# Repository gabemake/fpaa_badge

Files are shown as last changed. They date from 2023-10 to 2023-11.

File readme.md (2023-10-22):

# FPAA Add-on for SuperCon 2023 badge

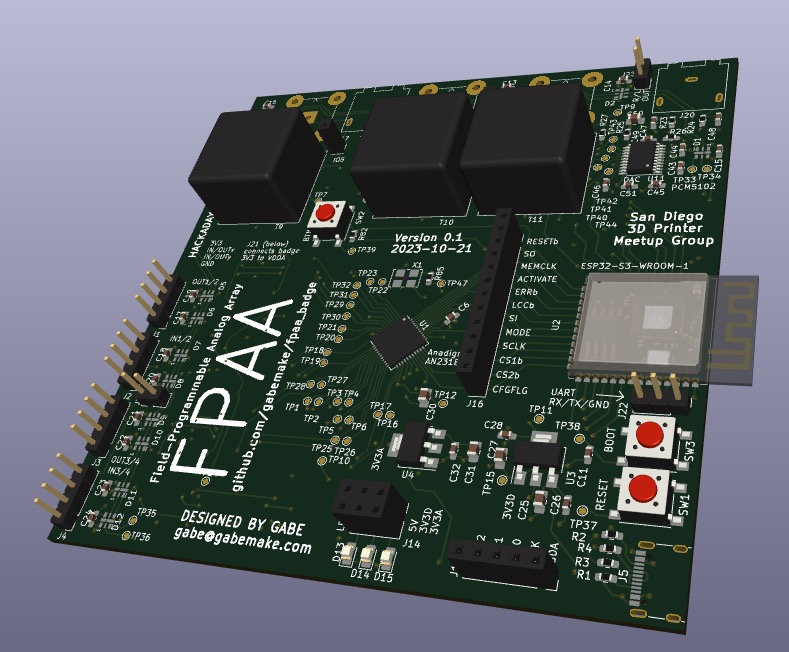
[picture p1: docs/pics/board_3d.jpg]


## SuperCon Badge info
Main article: https://hackaday.com/2023/10/18/2023-hackaday-supercon-badge-welcome-to-the-vectorscope/

Key points:
- RP2040 with DAC/ADC connected to PIOs
- Round display also on PIOs
- Micropython based SW

## FPAA Addon concept

What is an FPAA?
- Field-Programmable Analog Array
- Configurable array of analog components
  - Gain
  - Filter
  - Mix
  - more...
- 4 differential I and O ports
- 3 bidirectional differential ports
- SPI-ish configuration interface
- a.k.a. dpASP
- Datasheet: https://www.anadigm.com/_doc/DS231000-U001.pdf

Other things on the board:
- Connectors and single-to-differential conversion matching to badge IO
- ESP32-S3 to program FPAA (via web or otherwise)
- RBGLEDs all the way around
- a button
- BNC connectors + 3.5mm jack for external inputs or output
- SD Card reader

What to do with the addon?
- Figure out how to program and use a FPAA
- Maybe do a cool windows media player -like visualizer for music
- Get lots of practice soldering 0603 resistors

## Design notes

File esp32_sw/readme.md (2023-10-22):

# ESP32-S3 Software

Not yet started, but this is what I want to build:
- Simple web interface to upload config files for FPAA
- FPAA configuration interface (bit-bang SPI)
- RGB LED web interface (maybe tie in with FPAA configuration)
- ZRNA API (eventually)
- Web based scope to .wav converter (http://bummsn.de/osc_txt/)
- File manager for SD card (for wav files, etc.)
- Playback of .wav files via I2S DAC
- Custom SW for I2C/GPIO header
- Make button do something
- USB Host?
- Serial terminal?

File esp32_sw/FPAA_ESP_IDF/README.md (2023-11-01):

# FPAA Badge ESP32-S3 code

This code is based on a bunch of examples from the ESP-IDF github repo. 

file_server example is used to manage the web interface.
sdmmc is used to manage the file storage on the SD card (FAT FS for PC compatibility)
A highly modified spi_master LCD master example is used for the FPAA programming interface
I2S is used for the DAC.

### Status
- Wifi works with default SSID/IP, no configuration yet
- webserver is running with basic file management
- SPI writes can be sent with Program button on web page
- I2S initializes, but no file playback yet
- SD Card not working yet (need breakout board for dev kit)
- Internal SPI flash being used for web server
- platformio.ini locked to my serial port name, since my mac is picky

### TODO

in no particular order...

- add SD card and spi flash support
- add Wifi customization/configuration
- add SD card wifi configuration
- add background task for .wav playback
- add osc_wav page for text/drawing .wav "rendering"
- add basic RGB LED support
- test FPAA configuration
- add ace.js for file editing
- add RGB LED dynamic lighting for port enables, etc.
- add fun LED patterns
- add I2C to badge
- add button functionality (play/pause DAC?)

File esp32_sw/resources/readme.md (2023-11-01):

## Resources

In this folder, we have the following:
- `esp32-s3-devkitc-1-n8r2.json` file to add to `~/.platformio/boards`
- `test_mixer.ahf` as an example FPAA programming file

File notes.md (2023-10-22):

References:
- Differential to single-ended
  - https://www.analog.com/en/analog-dialogue/raqs/raq-issue-145.html

- ADC driver
  - https://www.analog.com/en/technical-articles/adc-driving-single-ended-to-differential-conversion.html

- FPAA Datasheet
  - https://www.anadigm.com/_doc/DS231000-U001.pdf

- FPAA User Manual
  - https://www.anadigm.com/_doc/UM000231-U001.pdf

- FPAA Product Page
  - https://www.anadigm.com/an231e04.asp

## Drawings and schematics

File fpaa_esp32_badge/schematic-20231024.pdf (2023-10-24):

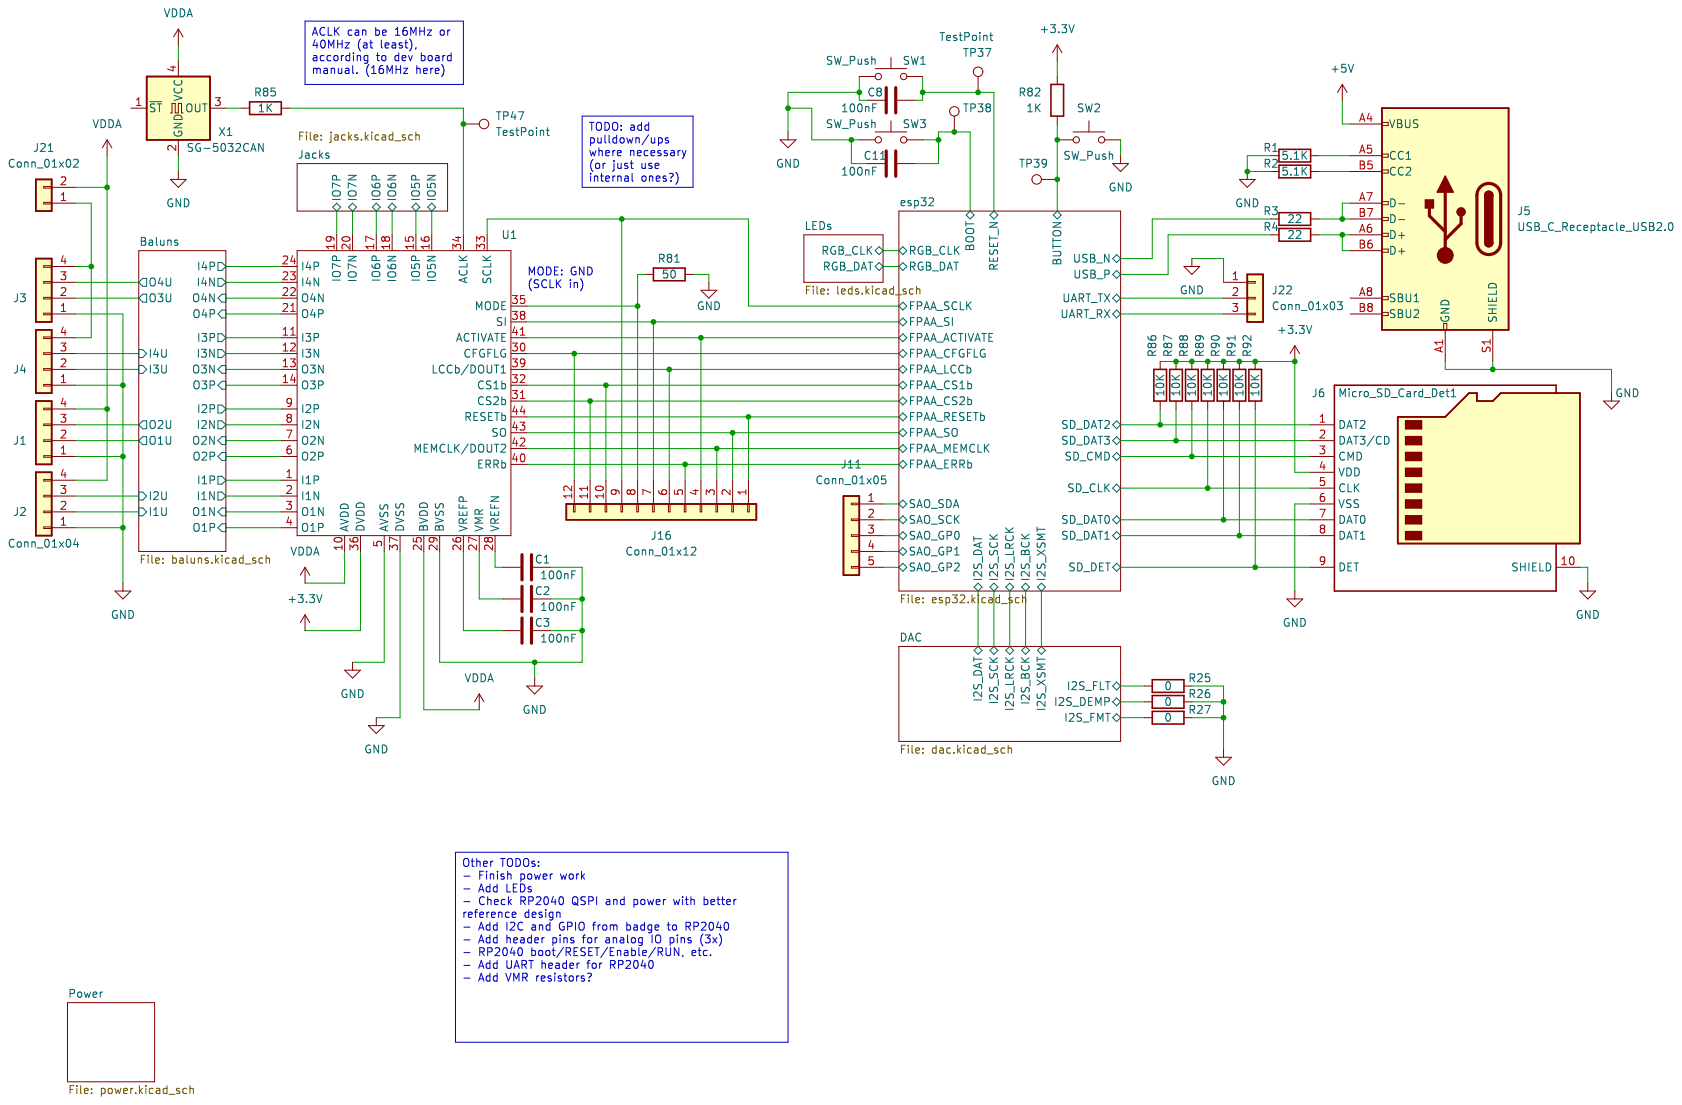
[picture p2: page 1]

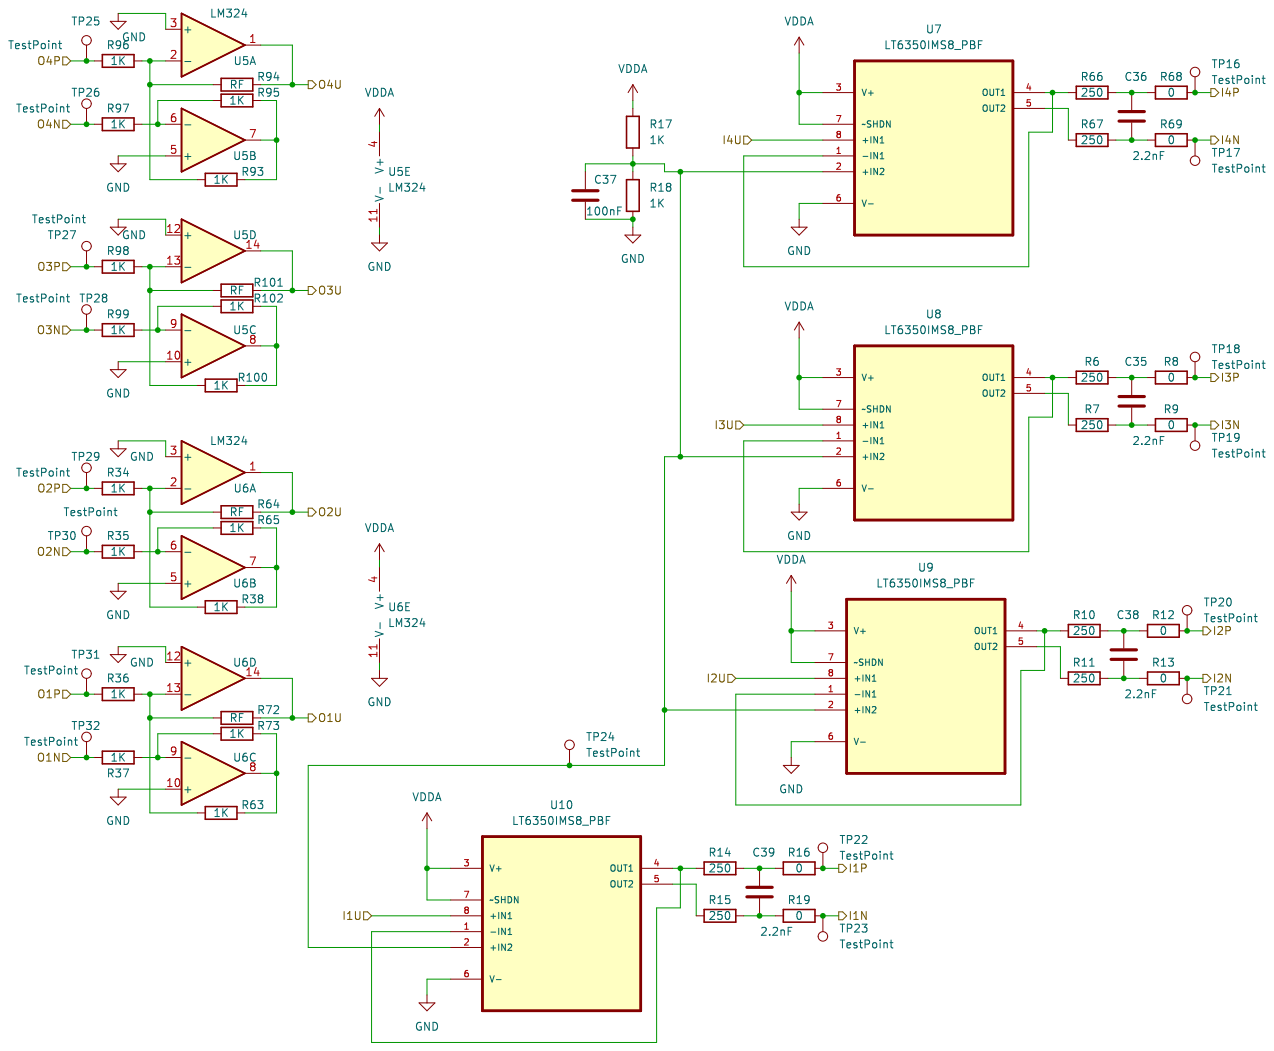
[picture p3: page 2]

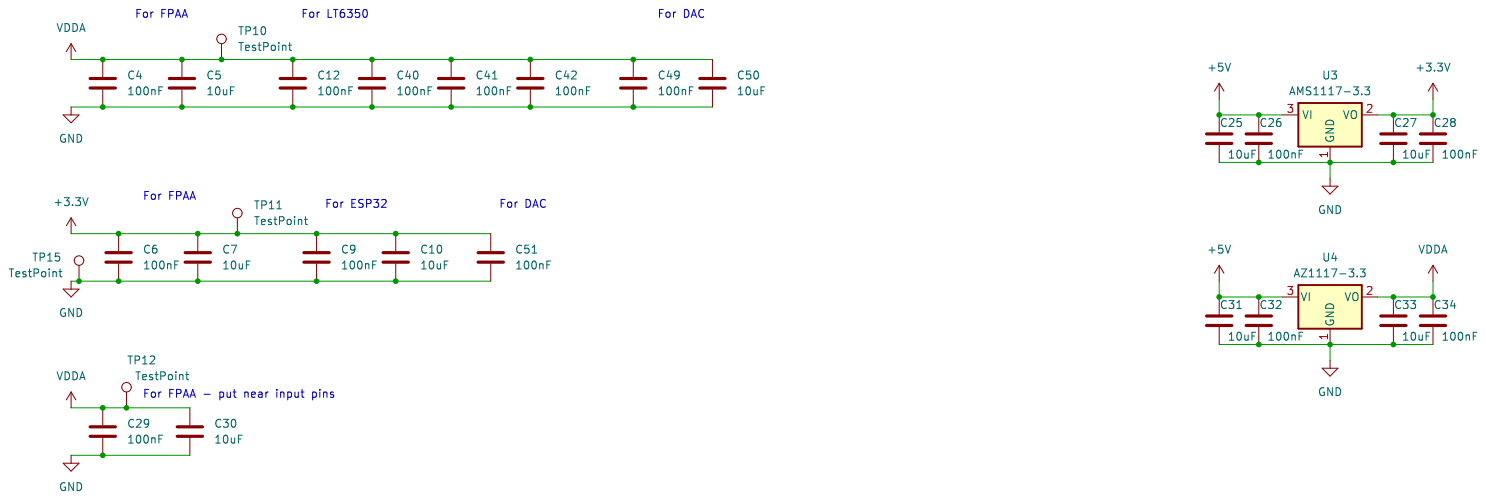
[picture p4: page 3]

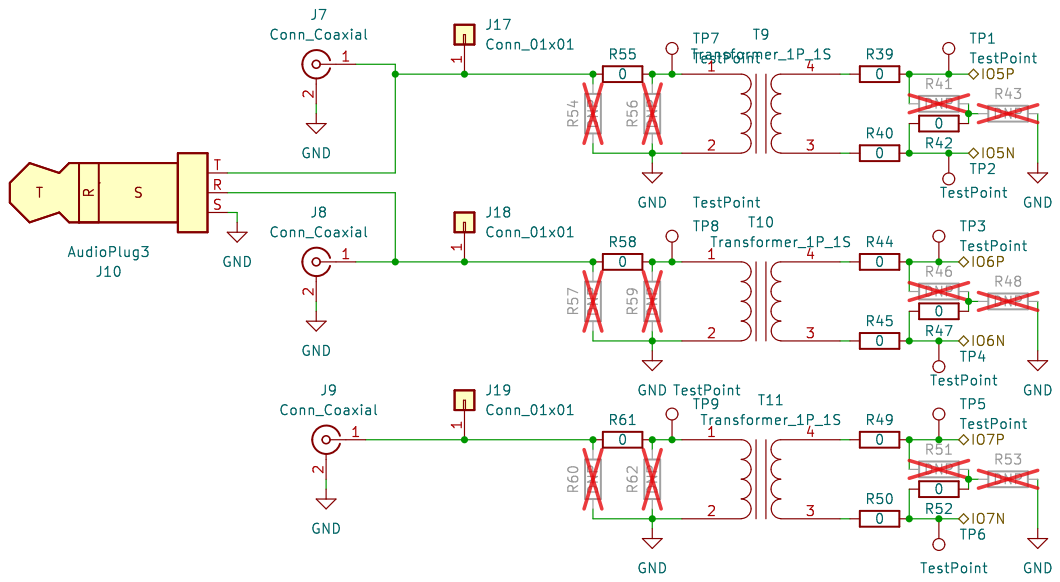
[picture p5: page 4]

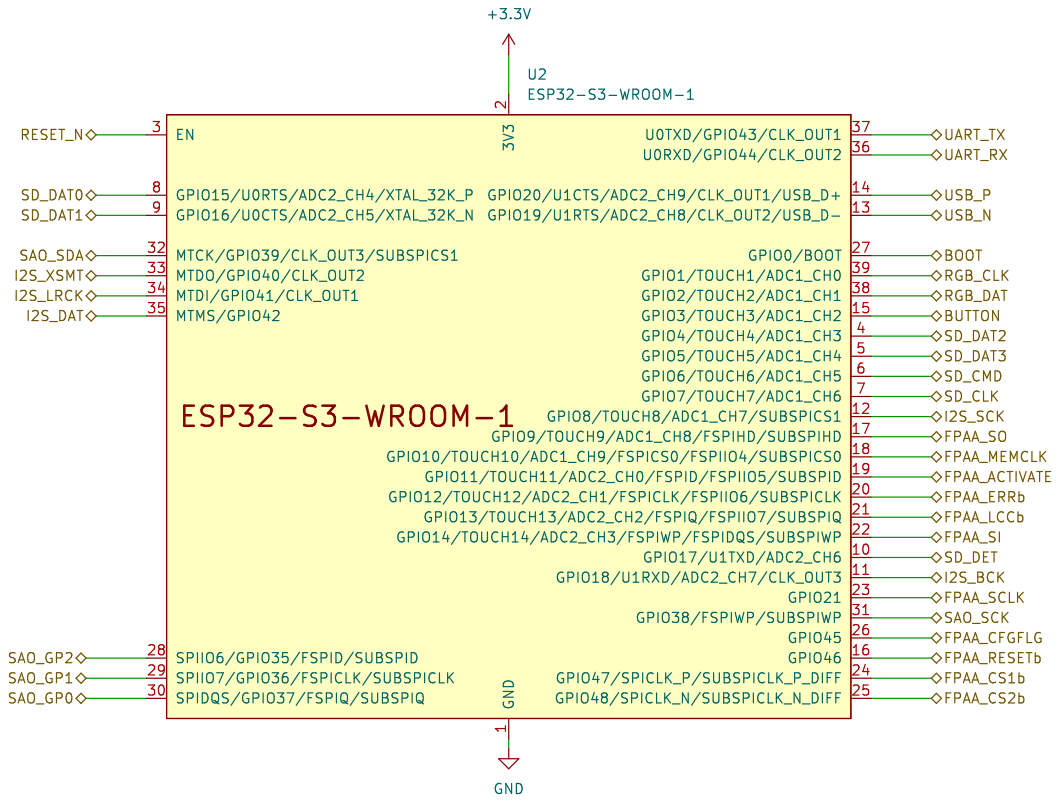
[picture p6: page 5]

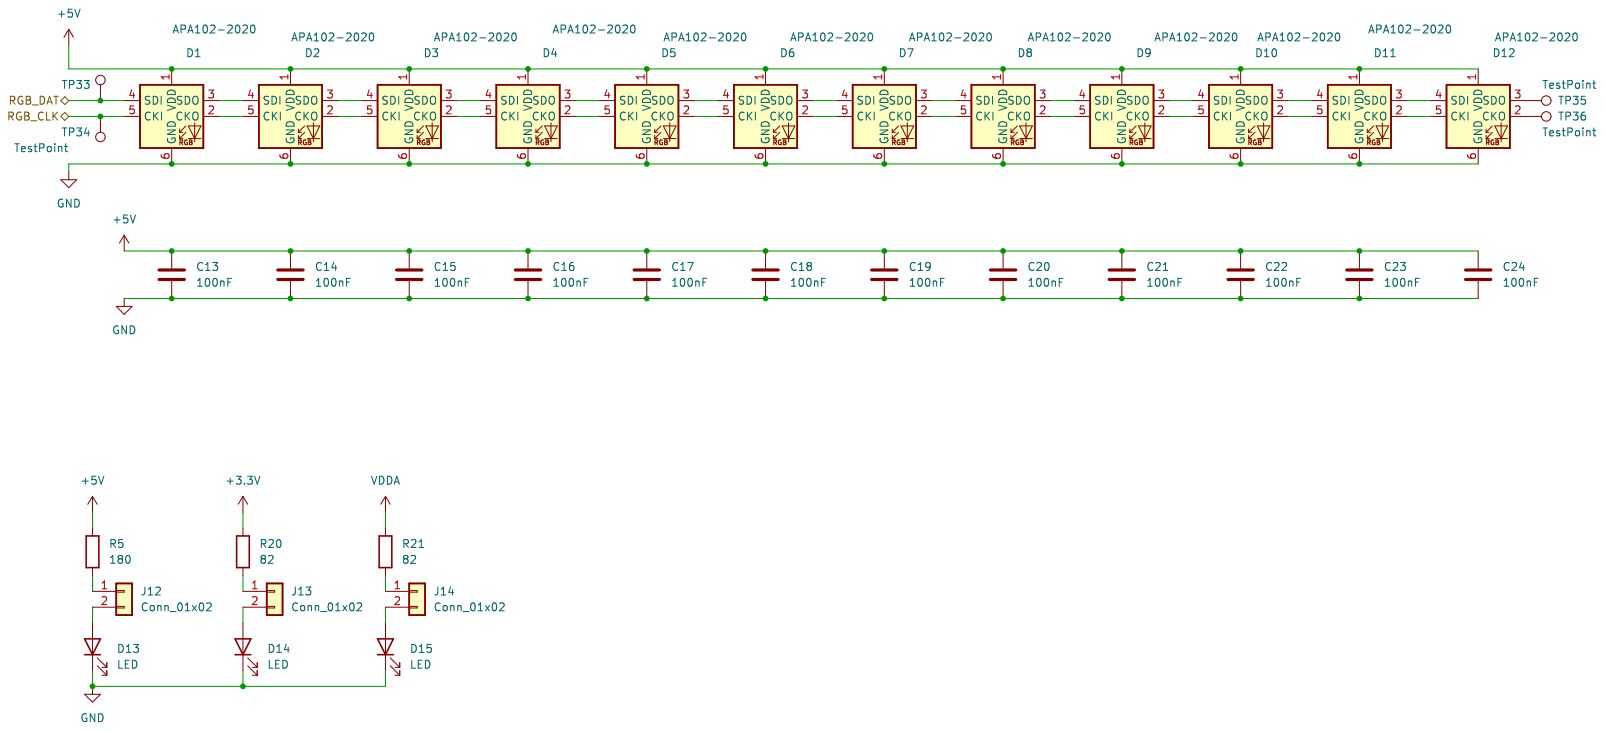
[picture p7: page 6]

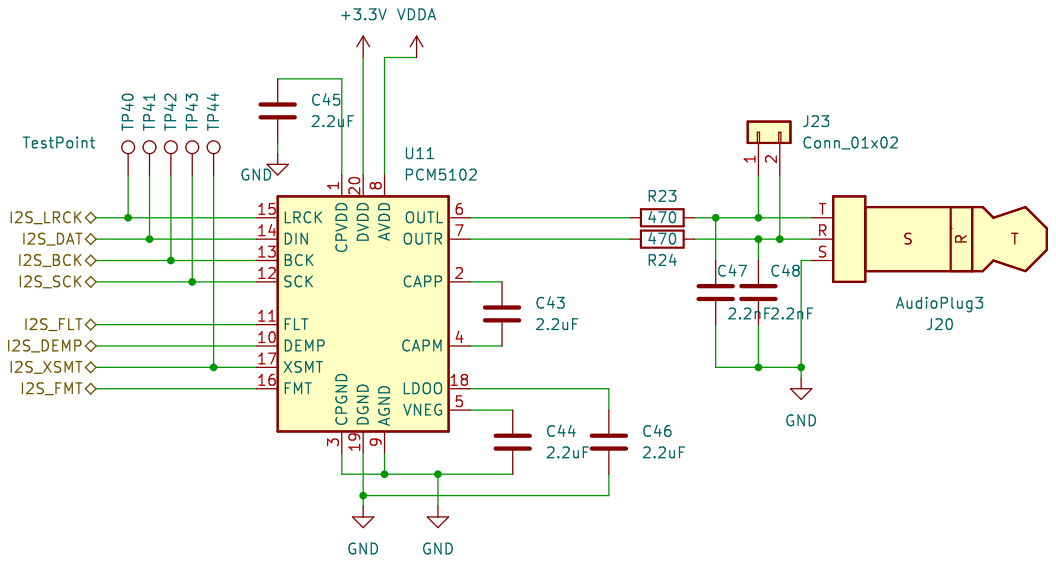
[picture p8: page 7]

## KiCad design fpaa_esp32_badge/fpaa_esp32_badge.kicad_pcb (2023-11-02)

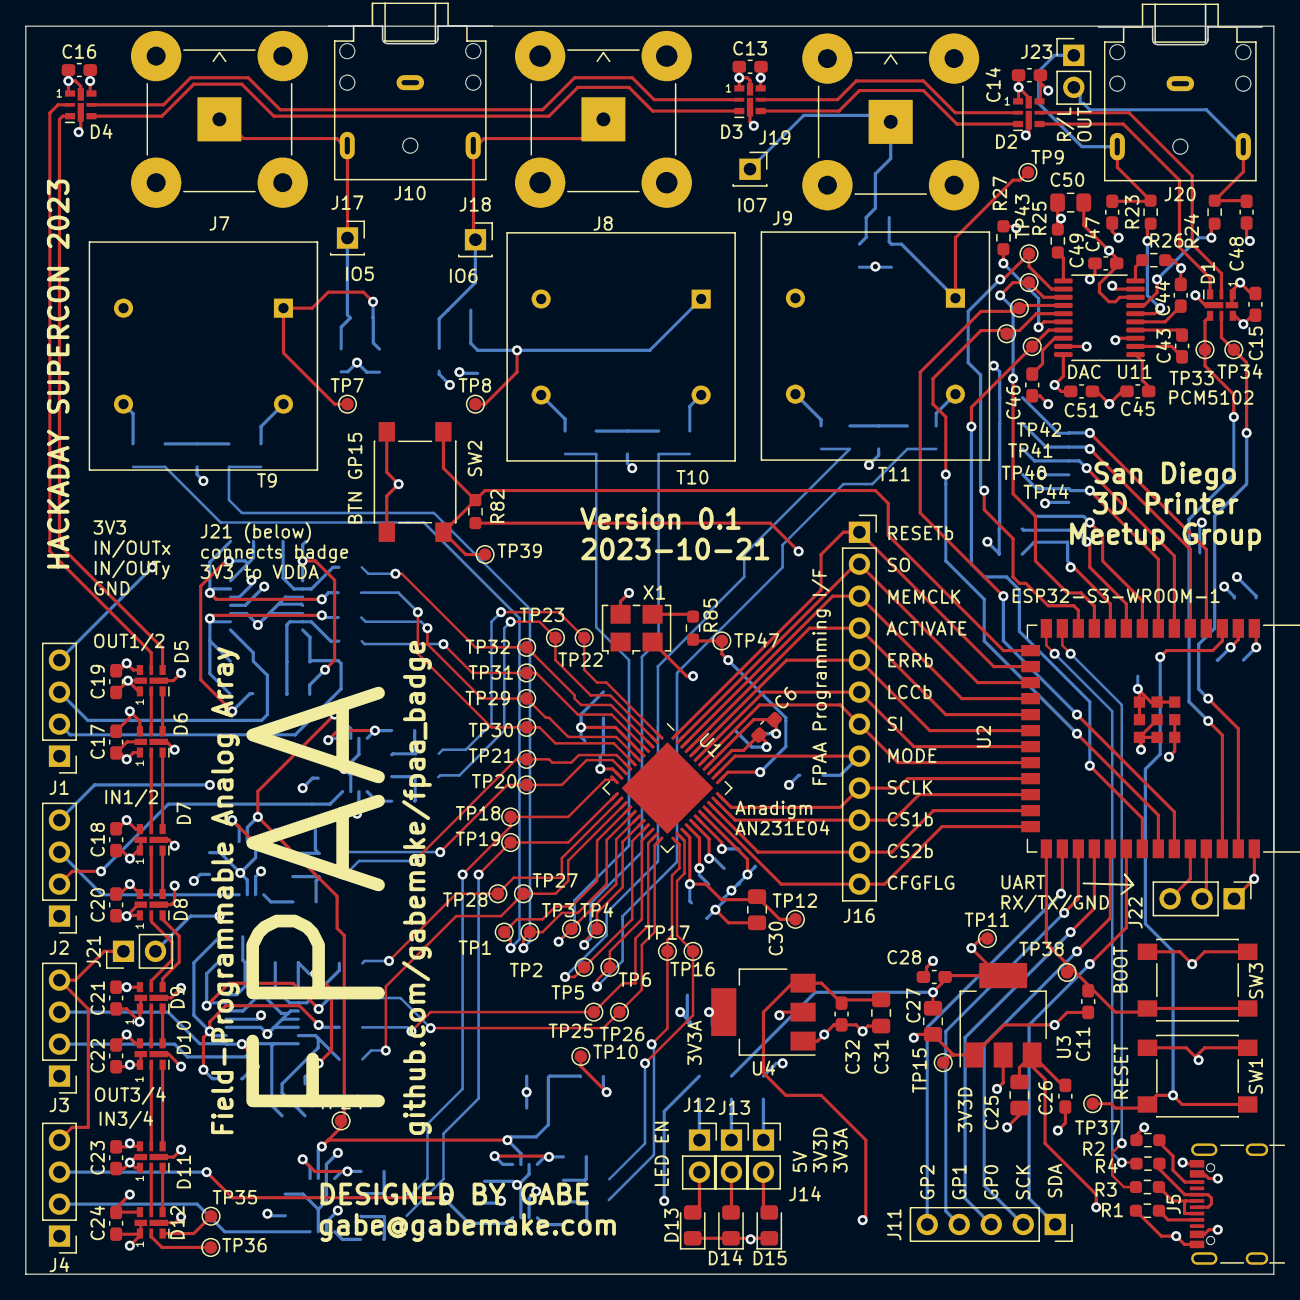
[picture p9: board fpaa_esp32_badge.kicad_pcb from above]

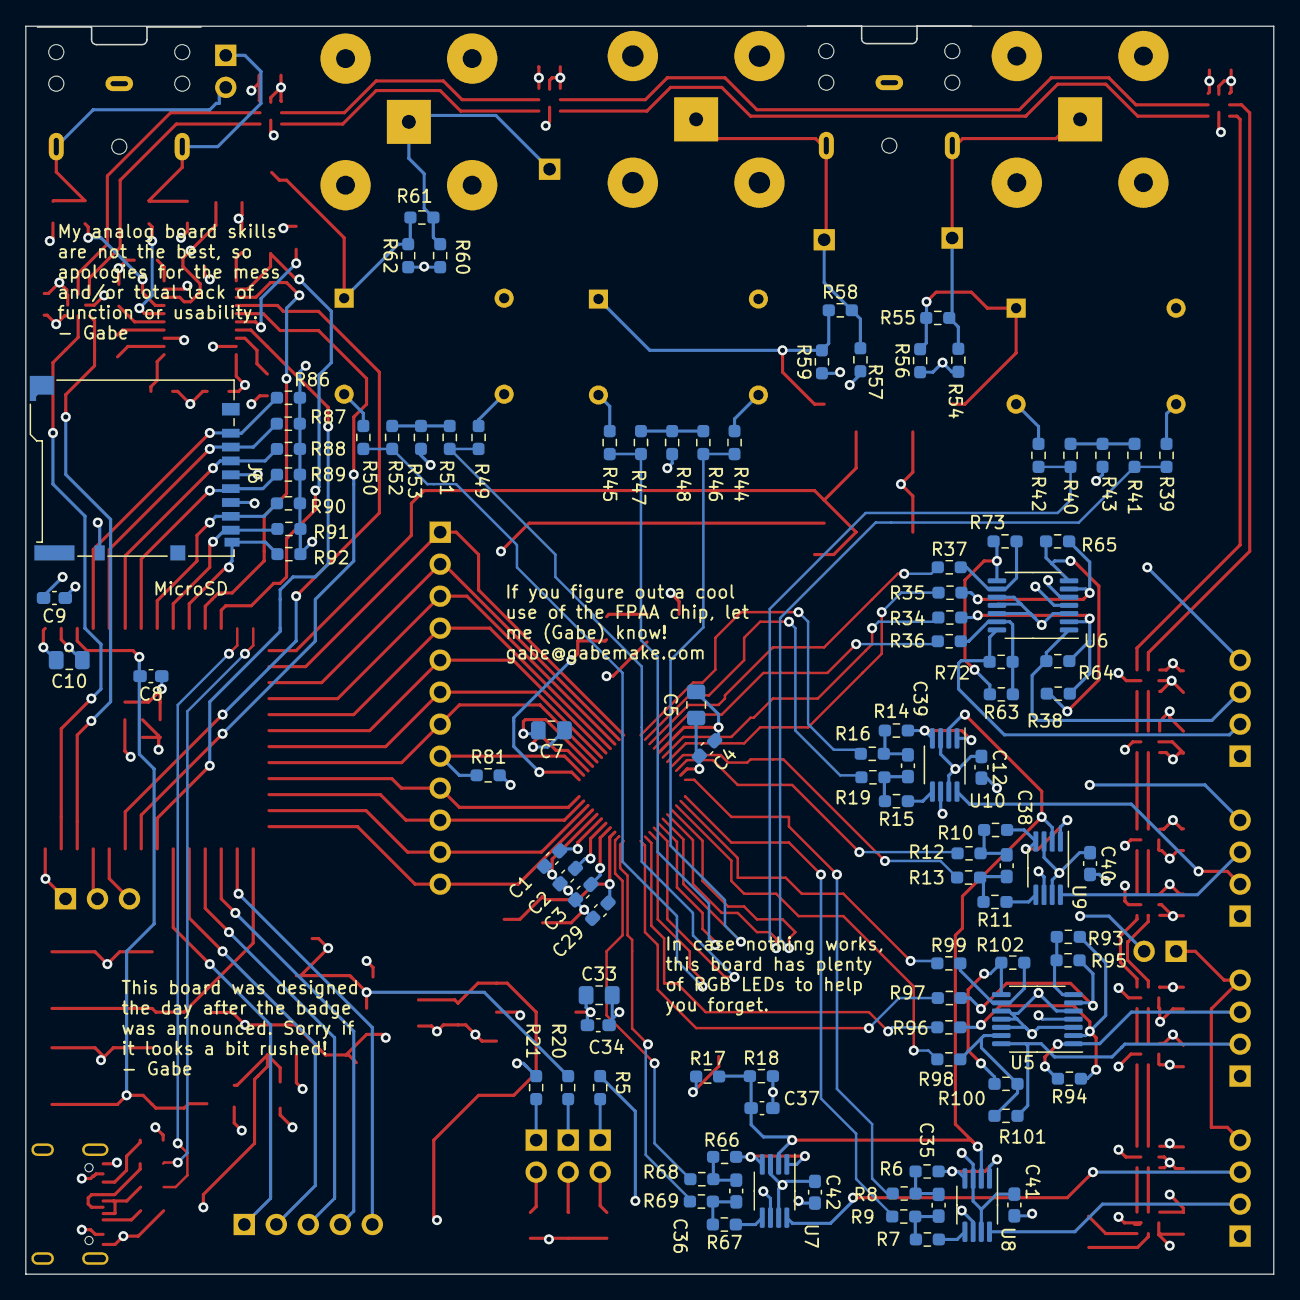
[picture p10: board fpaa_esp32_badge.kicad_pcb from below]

Board: 4 copper layers, 99.1 x 99.1 mm, 233 parts (101 on the bottom side), 168 nets.

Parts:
C1, C2, C3, C4, C6, C8, C9, C11, C12, C13, C14, C15, C16, C17, C18, C19, C20, C21, C22, C23, C24, C26, C28, C29, C32, C34, C37, C40, C41, C42, C49, C51: 100nF; C_0603_1608Metric_Pad1.08x0.95mm_HandSolder
C5, C7, C10, C25, C27, C30, C31, C33, C50: 10uF; C_0805_2012Metric_Pad1.18x1.45mm_HandSolder
C35, C36, C38, C39, C47, C48: 2.2nF; C_0603_1608Metric_Pad1.08x0.95mm_HandSolder
C43, C44, C45, C46: 2.2uF; C_0603_1608Metric_Pad1.08x0.95mm_HandSolder
D1, D2, D3, D4, D5, D6, D7, D8, D9, D10, D11, D12: APA102-2020; LED-APA102-2020
D13, D14, D15: LED; LED_0805_2012Metric_Pad1.15x1.40mm_HandSolder
J1, J2, J3, J4: Conn_01x04; PinHeader_1x04_P2.54mm_Vertical
J5: USB_C_Receptacle_USB2.0; USB_C_Receptacle_GCT_USB4105-xx-A_16P_TopMnt_Horizontal
J6: Micro_SD_Card_Det1; microSD_HC_Hirose_DM3BT-DSF-PEJS
J7, J9: Conn_Coaxial; BNC_TEConnectivity_1478035_Horizontal
J8: Conn_Coaxial; BNC_Molex_SD-73131-024_Horizontal
J10, J20: AudioPlug3; Jack_3.5mm_CUI_SJ1-3523N_Horizontal
J11: Conn_01x05; PinSocket_1x05_P2.54mm_Vertical
J12, J13, J14: Conn_01x02; PinSocket_1x02_P2.54mm_Vertical
J16: Conn_01x12; PinSocket_1x12_P2.54mm_Vertical
J17, J18, J19: Conn_01x01; PinSocket_1x01_P2.54mm_Vertical
J21, J23: Conn_01x02; PinHeader_1x02_P2.54mm_Vertical
J22: Conn_01x03; PinHeader_1x03_P2.54mm_Vertical
R1, R2: 5.1K; R_0603_1608Metric_Pad0.98x0.95mm_HandSolder
R3, R4: 22; R_0603_1608Metric_Pad0.98x0.95mm_HandSolder
R5: 180; R_0603_1608Metric_Pad0.98x0.95mm_HandSolder
R6, R7, R10, R11, R14, R15, R66, R67: 250; R_0603_1608Metric_Pad0.98x0.95mm_HandSolder
R8, R9, R12, R13, R16, R19, R25, R26, R27, R39, R40, R42, R44, R45, R47, R49, R50, R52, R55, R58, R61, R68, R69: 0; R_0603_1608Metric_Pad0.98x0.95mm_HandSolder
R17, R18, R34, R35, R36, R37, R38, R63, R65, R73, R82, R85, R93, R95, R96, R97, R98, R99, R100, R102: 1K; R_0603_1608Metric_Pad0.98x0.95mm_HandSolder
R20, R21: 82; R_0603_1608Metric_Pad0.98x0.95mm_HandSolder
R23, R24: 470; R_0603_1608Metric_Pad0.98x0.95mm_HandSolder
R41, R43, R46, R48, R51, R53, R54, R56, R57, R59, R60, R62: DNP; R_0603_1608Metric_Pad0.98x0.95mm_HandSolder
R64, R72, R94, R101: RF; R_0603_1608Metric_Pad0.98x0.95mm_HandSolder
R81: 50; R_0603_1608Metric_Pad0.98x0.95mm_HandSolder
R86, R87, R88, R89, R90, R91, R92: 10K; R_0603_1608Metric_Pad0.98x0.95mm_HandSolder
SW1, SW2, SW3: SW_Push; SW_SPST_PTS645
T9, T10, T11: Transformer_1P_1S; Transformer_NF_ETAL_1-1_P1200
TP1, TP2, TP3, TP4, TP5, TP6, TP7, TP8, TP9, TP10, TP11, TP12, TP15, TP16, TP17, TP18, TP19, TP20, TP21, TP22, TP23, TP24, TP25, TP26, TP27, TP28, TP29, TP30, TP31, TP32, TP33, TP34, TP35, TP36, TP37, TP38, TP39, TP40, TP41, TP42, TP43, TP44, TP47: TestPoint; TestPoint_Pad_D1.0mm
U1: QFN-44-1EP_7x7mm_P0.5mm_EP5.15x5.15mm
U2: ESP32-S3-WROOM-1
U3: AMS1117-3.3; SOT-223-3_TabPin2
U4: AZ1117-3.3; SOT-223-3_TabPin2
U5, U6: LM324; TSSOP-14_4.4x5mm_P0.65mm
U7, U8, U9, U10: LT6350IMS8_PBF; MSOP-8_3x3mm_P0.65mm
U11: PCM5102; TSSOP-20_4.4x6.5mm_P0.65mm
X1: SG-5032CAN; Oscillator_SMD_SeikoEpson_SG8002LB-4Pin_5.0x3.2mm

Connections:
+3.3V: C6.1, C7.1, C9.1, C10.1, C27.1, C28.1, C51.1, J6.4 (VDD), R20.1, R82.1, R86.2, R87.2, R88.2, R89.2, R90.2, R91.2, R92.2, TP11.1, U1.36 (DVDD), U2.2 (3V3), U3.2 (VO), U11.20 (DVDD)
+5V: C13.1, C14.1, C15.1, C16.1, C17.1, C18.1, C19.1, C20.1, C21.1, C22.1, C23.1, C24.1, C25.1, C26.1, C31.1, C32.1, D1.1 (VDD), D2.1 (VDD), D3.1 (VDD), D4.1 (VDD), D5.1 (VDD), D6.1 (VDD), D7.1 (VDD), D8.1 (VDD), D9.1 (VDD), D10.1 (VDD), D11.1 (VDD), D12.1 (VDD), J5.A4 (VBUS), J5.A9 (VBUS), J5.B4 (VBUS), J5.B9 (VBUS), R5.1, U3.3 (VI), U4.3 (VI)
/Baluns/I1N: R19.2, TP23.1, U1.2 (I1N)
/Baluns/I1P: R16.2, TP22.1, U1.1 (I1P)
/Baluns/I1U: J2.2, U10.8 (+IN1)
/Baluns/I2N: R13.2, TP21.1, U1.8 (I2N)
/Baluns/I2P: R12.2, TP20.1, U1.9 (I2P)
/Baluns/I2U: J2.3, U9.8 (+IN1)
/Baluns/I3N: R9.2, TP19.1, U1.12 (I3N)
/Baluns/I3P: R8.2, TP18.1, U1.11 (I3P)
/Baluns/I3U: J4.2, U8.8 (+IN1)
/Baluns/I4N: R69.2, TP17.1, U1.23 (I4N)
/Baluns/I4P: R68.2, TP16.1, U1.24 (I4P)
/Baluns/I4U: J4.3, U7.8 (+IN1)
/Baluns/O1N: R37.1, TP32.1, U1.3 (O1N)
/Baluns/O1P: R36.1, TP31.1, U1.4 (O1P)
/Baluns/O1U: J1.2, R72.2, U6.14
/Baluns/O2N: R35.1, TP30.1, U1.7 (O2N)
/Baluns/O2P: R34.1, TP29.1, U1.6 (O2P)
/Baluns/O2U: J1.3, R64.2, U6.1
/Baluns/O3N: R99.1, TP28.1, U1.13 (O3N)
/Baluns/O3P: R98.1, TP27.1, U1.14 (O3P)
/Baluns/O3U: J3.2, R101.2, U5.14
/Baluns/O4N: R97.1, TP26.1, U1.22 (O4N)
/Baluns/O4P: R96.1, TP25.1, U1.21 (O4P)
/Baluns/O4U: J3.3, R94.2, U5.1
/DAC/I2S_BCK: TP42.1, U2.11 (GPIO18/U1RXD/ADC2_CH7/CLK_OUT3), U11.13 (BCK)
/DAC/I2S_DAT: TP41.1, U2.35 (MTMS/GPIO42), U11.14 (DIN)
/DAC/I2S_DEMP: R26.1, U11.10 (DEMP)
/DAC/I2S_FLT: R25.1, U11.11 (FLT)
/DAC/I2S_FMT: R27.1, U11.16 (FMT)
/DAC/I2S_LRCK: TP40.1, U2.34 (MTDI/GPIO41/CLK_OUT1), U11.15 (LRCK)
/DAC/I2S_SCK: TP43.1, U2.12 (GPIO8/TOUCH8/ADC1_CH7/SUBSPICS1), U11.12 (SCK)
/DAC/I2S_XSMT: TP44.1, U2.33 (MTDO/GPIO40/CLK_OUT2), U11.17 (XSMT)
/Jacks/IO5N: R40.2, R42.1, TP2.1, U1.16 (IO5N)
/Jacks/IO5P: R39.2, R41.1, TP1.1, U1.15 (IO5P)
/Jacks/IO6N: R45.2, R47.1, TP4.1, U1.18 (IO6N)
/Jacks/IO6P: R44.2, R46.1, TP3.1, U1.17 (IO6P)
/Jacks/IO7N: R50.2, R52.1, TP6.1, U1.20 (IO7N)
/Jacks/IO7P: R49.2, R51.1, TP5.1, U1.19 (IO7P)
/LEDs/RGB_CLK: D1.5 (CKI), TP34.1, U2.39 (GPIO1/TOUCH1/ADC1_CH0)
/LEDs/RGB_DAT: D1.4 (SDI), TP33.1, U2.38 (GPIO2/TOUCH2/ADC1_CH1)
/esp32/BOOT: C11.2, SW3.1, TP38.1, U2.27 (GPIO0/BOOT)
/esp32/BUTTON: R82.2, SW2.1, TP39.1, U2.15 (GPIO3/TOUCH3/ADC1_CH2)
/esp32/FPAA_ACTIVATE: J16.4, U1.41 (ACTIVATE), U2.19 (GPIO11/TOUCH11/ADC2_CH0/FSPID/FSPIIO5/S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)
/esp32/FPAA_CFGFLG: J16.12, U1.30 (CFGFLG), U2.26 (GPIO45)
/esp32/FPAA_CS1b: J16.10, U1.32 (CS1b), U2.24 (GPIO47/SPICLK_P/SUBSPICLK_P_DIFF)
/esp32/FPAA_CS2b: J16.11, U1.31 (CS2b), U2.25 (GPIO48/SPICLK_N/SUBSPICLK_N_DIFF)
/esp32/FPAA_ERRb: J16.5, U1.40 (ERRb), U2.20 (GPIO12/TOUCH12/ADC2_CH1/FSPICLK/FSPIIO6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)
/esp32/FPAA_LCCb: J16.6, U1.39 (LCCb/DOUT1), U2.21 (GPIO13/TOUCH13/ADC2_CH2/FSPIQ/FSPIIO7/S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)
/esp32/FPAA_MEMCLK: J16.3, U1.42 (MEMCLK/DOUT2), U2.18 (GPIO10/TOUCH10/ADC1_CH9/FSPICS0/FSPIIO4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)
/esp32/FPAA_RESETb: J16.1, U1.44 (RESETb), U2.16 (GPIO46)
/esp32/FPAA_SCLK: J16.9, U1.33 (SCLK), U2.23 (GPIO21)
/esp32/FPAA_SI: J16.7, U1.38 (SI), U2.22 (GPIO14/TOUCH14/ADC2_CH3/FSPIWP/FSPIDQS/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)
/esp32/FPAA_SO: J16.2, U1.43 (SO), U2.17 (GPIO9/TOUCH9/ADC1_CH8/FSPIHD/SUBSPIHD)
/esp32/RESET_N: C8.2, SW1.1, TP37.1, U2.3 (EN)
/esp32/SAO_GP0: J11.3, U2.30 (SPIDQS/GPIO37/FSPIQ/SUBSPIQ)
/esp32/SAO_GP1: J11.4, U2.29 (SPIIO7/GPIO36/FSPICLK/SUBSPICLK)
/esp32/SAO_GP2: J11.5, U2.28 (SPIIO6/GPIO35/FSPID/SUBSPID)
/esp32/SAO_SCK: J11.2, U2.31 (GPIO38/FSPIWP/SUBSPIWP)
/esp32/SAO_SDA: J11.1, U2.32 (MTCK/GPIO39/CLK_OUT3/SUBSPICS1)
/esp32/SD_CLK: J6.5 (CLK), R89.1, U2.7 (GPIO7/TOUCH7/ADC1_CH6)
/esp32/SD_CMD: J6.3 (CMD), R88.1, U2.6 (GPIO6/TOUCH6/ADC1_CH5)
/esp32/SD_DAT0: J6.7 (DAT0), R90.1, U2.8 (GPIO15/U0RTS/ADC2_CH4/XTAL_32K_P)
/esp32/SD_DAT1: J6.8 (DAT1), R91.1, U2.9 (GPIO16/U0CTS/ADC2_CH5/XTAL_32K_N)
/esp32/SD_DAT2: J6.1 (DAT2), R86.1, U2.4 (GPIO4/TOUCH4/ADC1_CH3)
/esp32/SD_DAT3: J6.2 (DAT3/CD), R87.1, U2.5 (GPIO5/TOUCH5/ADC1_CH4)
/esp32/SD_DET: J6.9 (DET), R92.1, U2.10 (GPIO17/U1TXD/ADC2_CH6)
/esp32/UART_RX: J22.3, U2.36 (U0RXD/GPIO44/CLK_OUT2)
/esp32/UART_TX: J22.2, U2.37 (U0TXD/GPIO43/CLK_OUT1)
/esp32/USB_N: R3.1, U2.13 (GPIO19/U1RTS/ADC2_CH8/CLK_OUT2/USB_D-)
/esp32/USB_P: R4.1, U2.14 (GPIO20/U1CTS/ADC2_CH9/CLK_OUT1/USB_D+)
GND: C1.2, C2.1, C3.2, C4.2, C5.2, C6.2, C7.2, C8.1, C9.2, C10.2, C11.1, C12.2, C13.2, C14.2, C15.2, C16.2, C17.2, C18.2, C19.2, C20.2, C21.2, C22.2, C23.2, C24.2, C25.2, C26.2, C27.2, C28.2, C29.2, C30.2, C31.2, C32.2, C33.2, C34.2, C37.2, C40.2, C41.2, C42.2, C44.2, C45.2, C46.2, C47.2, C48.2, C49.2, C50.2, C51.2, D1.6 (GND), D2.6 (GND), D3.6 (GND), D4.6 (GND), D5.6 (GND), D6.6 (GND), D7.6 (GND), D8.6 (GND), D9.6 (GND), D10.6 (GND), D11.6 (GND), D12.6 (GND), D13.1 (K), D14.1 (K), D15.1 (K), J1.1, J2.1, J3.1, J4.1, J5.A1 (GND), J5.A12 (GND), J5.B1 (GND), J5.B12 (GND), J5.S1 (SHIELD), J6.6 (VSS), J6.10 (SHIELD), J7.2 (Ext), J8.2 (Ext), J9.2 (Ext), J10.S, J20.S, J22.1, R1.1, R2.1, R18.2, R25.2, R26.2, R27.2, R43.2, R48.2, R53.2, R54.1, R56.1, R57.1, R59.1, R60.1, R62.1, R81.2, SW1.2, SW2.2, SW3.2, TP15.1, U1.5 (AVSS), U1.29 (BVSS), U1.37 (DVSS), U2.1 (GND), U2.40 (GND), U2.41 (GND), U3.1 (GND), U4.1 (GND), U5.3 (+), U5.5 (+), U5.10 (+), U5.11 (V-), U5.12 (+), U6.3 (+), U6.5 (+), U6.10 (+), U6.11 (V-), U6.12 (+), U7.6 (V-), U8.6 (V-), U9.6 (V-), U10.6 (V-), U11.3 (CPGND), U11.9 (AGND), U11.19 (DGND), X1.2 (GND)
unnamed: C35.1, R6.2, R8.1
unnamed: C35.2, R7.2, R9.1
unnamed: C36.1, R66.2, R68.1
unnamed: C36.2, R67.2, R69.1
unnamed: C38.1, R10.2, R12.1
unnamed: C38.2, R11.2, R13.1
unnamed: C39.1, R14.2, R16.1
unnamed: C39.2, R15.2, R19.1
unnamed: D1.2 (CKO), D2.5 (CKI)
unnamed: D1.3 (SDO), D2.4 (SDI)
unnamed: D2.2 (CKO), D3.5 (CKI)
unnamed: D2.3 (SDO), D3.4 (SDI)
unnamed: D3.2 (CKO), D4.5 (CKI)
unnamed: D3.3 (SDO), D4.4 (SDI)
unnamed: D4.2 (CKO), D5.5 (CKI)
unnamed: D4.3 (SDO), D5.4 (SDI)
unnamed: D5.2 (CKO), D6.5 (CKI)
unnamed: D5.3 (SDO), D6.4 (SDI)
unnamed: D6.2 (CKO), D7.5 (CKI)
unnamed: D6.3 (SDO), D7.4 (SDI)
unnamed: D7.2 (CKO), D8.5 (CKI)
unnamed: D7.3 (SDO), D8.4 (SDI)
unnamed: D8.2 (CKO), D9.5 (CKI)
unnamed: D8.3 (SDO), D9.4 (SDI)
unnamed: D9.2 (CKO), D10.5 (CKI)
unnamed: D10.2 (CKO), D11.5 (CKI)
unnamed: D9.3 (SDO), D10.4 (SDI)
unnamed: D10.3 (SDO), D11.4 (SDI)
unnamed: D11.2 (CKO), D12.5 (CKI)
unnamed: D11.3 (SDO), D12.4 (SDI)
unnamed: D12.2 (CKO), TP36.1
unnamed: D12.3 (SDO), TP35.1
unnamed: D13.2 (A), J12.2
unnamed: D14.2 (A), J13.2
unnamed: D15.2 (A), J14.2
unnamed: J5.A5 (CC1), R1.2
unnamed: J5.B5 (CC2), R2.2
unnamed: J5.A6 (D+), J5.B6 (D+), R4.2
unnamed: J5.A7 (D-), J5.B7 (D-), R3.2
unnamed: J12.1, R5.2
unnamed: J13.1, R20.2
unnamed: J14.1, R21.2
unnamed: J16.8, R81.1, U1.35 (MODE)
unnamed: J7.1 (In), J10.T, J17.1, R54.2, R55.1
unnamed: J8.1 (In), J10.R, J18.1, R57.2, R58.1
unnamed: J9.1 (In), J19.1, R60.2, R61.1
unnamed: J3.4, J4.4, J21.1
unnamed: C47.1, J20.T, J23.1, R23.2
unnamed: C48.1, J20.R, J23.2, R24.2
unnamed: R38.2, R65.2, U6.7
unnamed: R41.2, R42.2, R43.1
unnamed: R46.2, R47.2, R48.1
unnamed: R51.2, R52.2, R53.1
unnamed: R63.2, R73.2, U6.8
unnamed: R93.2, R95.2, U5.7
unnamed: R100.2, R102.2, U5.8
unnamed: R55.2, R56.2, T9.1 (AA), TP7.1
unnamed: R40.1, T9.3 (SA)
unnamed: R39.1, T9.4 (SB)
unnamed: R58.2, R59.2, T10.1 (AA), TP8.1
unnamed: R45.1, T10.3 (SA)
unnamed: R44.1, T10.4 (SB)
unnamed: R61.2, R62.2, T11.1 (AA), TP9.1
unnamed: R50.1, T11.3 (SA)
unnamed: R49.1, T11.4 (SB)
unnamed: R85.2, TP47.1, U1.34 (ACLK)
unnamed: C2.2, U1.27 (VMR)
unnamed: C1.1, U1.28 (VREFN)
unnamed: C3.1, U1.26 (VREFP)
unnamed: R93.1, R94.1, R96.2, U5.2 (-)
unnamed: R95.1, R97.2, U5.6 (-)
unnamed: R99.2, R102.1, U5.9 (-)
unnamed: R98.2, R100.1, R101.1, U5.13 (-)
unnamed: R34.2, R38.1, R64.1, U6.2 (-)
unnamed: R35.2, R65.1, U6.6 (-)
unnamed: R37.2, R73.1, U6.9 (-)
unnamed: R36.2, R63.1, R72.1, U6.13 (-)
unnamed: R66.1, U7.1 (-IN1), U7.4 (OUT1)
unnamed: R67.1, U7.5 (OUT2)
unnamed: R6.1, U8.1 (-IN1), U8.4 (OUT1)
unnamed: R7.1, U8.5 (OUT2)
unnamed: R10.1, U9.1 (-IN1), U9.4 (OUT1)
unnamed: R11.1, U9.5 (OUT2)
unnamed: C37.1, R17.2, R18.1, TP24.1, U7.2 (+IN2), U8.2 (+IN2), U9.2 (+IN2), U10.2 (+IN2)
unnamed: R14.1, U10.1 (-IN1), U10.4 (OUT1)
unnamed: R15.1, U10.5 (OUT2)
unnamed: C43.2, U11.4 (CAPM)
unnamed: C43.1, U11.2 (CAPP)
unnamed: C45.1, U11.1 (CPVDD)
unnamed: C46.1, U11.18 (LDOO)
unnamed: R23.1, U11.6 (OUTL)
unnamed: R24.1, U11.7 (OUTR)
unnamed: C44.1, U11.5 (VNEG)
unnamed: R85.1, X1.3 (OUT)
VDDA: C4.1, C5.1, C12.1, C29.1, C30.1, C33.1, C34.1, C40.1, C41.1, C42.1, C49.1, C50.1, J1.4, J2.4, J21.2, R17.1, R21.1, TP10.1, TP12.1, U1.10 (AVDD), U1.25 (BVDD), U4.2 (VO), U5.4 (V+), U6.4 (V+), U7.3 (V+), U7.7 (~SHDN), U8.3 (V+), U8.7 (~SHDN), U9.3 (V+), U9.7 (~SHDN), U10.3 (V+), U10.7 (~SHDN), U11.8 (AVDD), X1.4 (VCC)

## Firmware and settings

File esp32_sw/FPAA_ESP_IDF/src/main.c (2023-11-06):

#include "driver/gpio.h"
#include "sdkconfig.h"
#include "driver/uart.h"
#include "fpaa_esp_config.h"
#include "fpaa_spi.h"
#include "file_server.h"
#include "i2s_dac.h"
#include "sdcard.h"
#include "wifi.h"
#define BUF_SIZE (1024)



// handles
i2s_chan_handle_t i2s_handle;
spi_device_handle_t spi;

void init_uart() {
    /* Configure parameters of an UART driver,
     * communication pins and install the driver */
    uart_config_t uart_config = {
        .baud_rate = 115200,
        .data_bits = UART_DATA_8_BITS,
        .parity    = UART_PARITY_DISABLE,
        .stop_bits = UART_STOP_BITS_1,
        .flow_ctrl = UART_HW_FLOWCTRL_DISABLE
    };
    uart_param_config(UART_NUM_0, &uart_config);
    //uart_set_pin(UART_NUM_0, ECHO_TEST_TXD, ECHO_TEST_RXD, ECHO_TEST_RTS, ECHO_TEST_CTS);
    uart_set_pin(UART_NUM_0,UART_PIN_NO_CHANGE, UART_PIN_NO_CHANGE,UART_PIN_NO_CHANGE,UART_PIN_NO_CHANGE);
    uart_driver_install(UART_NUM_0, BUF_SIZE * 2, 0, 0, NULL, 0);
}

void init_gpio() {
    //zero-initialize the config structure.
    gpio_config_t io_conf = {};
    //disable interrupt
    io_conf.intr_type = GPIO_INTR_DISABLE;
    //set as output mode
    io_conf.mode = GPIO_MODE_OUTPUT;
    //bit mask of the pins that you want to set,e.g.GPIO18/19
    io_conf.pin_bit_mask = FPAA_OUTPUT_PINS;
    //disable pull-down mode
    io_conf.pull_down_en = 0;
    //disable pull-up mode
    io_conf.pull_up_en = 0;
    //configure GPIO with the given settings
    gpio_config(&io_conf);

    //disable interrupt
    io_conf.intr_type = GPIO_INTR_DISABLE;
    //set as output mode
    io_conf.mode = GPIO_MODE_INPUT;
    //bit mask of the pins that you want to set,e.g.GPIO18/19
    io_conf.pin_bit_mask = FPAA_HOLD_PINS;
    //disable pull-down mode
    io_conf.pull_down_en = 0;
    //disable pull-up mode
    io_conf.pull_up_en = 1;
    //configure GPIO with the given settings
    gpio_config(&io_conf);
}

void app_main()
{

    const char* base_path = "/data";


    //init uart
    init_uart();
    printf("\nUART Logging started! (if you can see this)\n");

    //start GPIO
    init_gpio();
    gpio_set_level(FPAA_CS2B_PIN, 1);

    // configure SD card
    printf("Setting up SD card (and LittleFS)\n");
    nvs_flash_init();
    mount_storage(base_path);

    //configure SPI interface
    printf("Setting up SPI\n");
    init_spi(&spi);

    //configure I2S peripheral
    printf("Setting up I2S (for DAC)\n");
    i2s_setup(&i2s_handle);

    //start WiFi
    printf("Starting WiFi AP\n");
    wifi_init_softap();

    //start webserver
    printf("Starting webserver\n");
    start_file_server(base_path, spi);

    //enabling FPAA
    printf("releasing FPAA reset\n");
    gpio_set_level(FPAA_RESETB_PIN, 1);

}

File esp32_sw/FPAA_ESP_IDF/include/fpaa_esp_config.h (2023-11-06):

#define BADGE_ESP_WIFI_SSID      "FPAA Badge"
#define BADGE_ESP_WIFI_PASS      "security through obscurity"
#define BADGE_ESP_WIFI_CHANNEL   11
#define BADGE_MAX_STA_CONN       10

#define FPAA_HOST    SPI2_HOST

#define FPAA_SO_PIN 9
#define FPAA_SI_PIN 14
#define FPAA_SCLK_PIN 21
#define FPAA_CS1B_PIN 47

#define FPAA_RESETB_PIN 46
#define FPAA_MEMCLK_PIN 10
#define FPAA_ACTIVATE_PIN 11
#define FPAA_ERRB_PIN 12
#define FPAA_LCCB_PIN 13
#define FPAA_CS2B_PIN 48
#define FPAA_CFGFLG_PIN 45
#define FPAA_OUTPUT_PINS  ((1ULL<<FPAA_RESETB_PIN) | (1ULL<<FPAA_CS2B_PIN))
#define FPAA_HOLD_PINS  (1ULL<<FPAA_ERRB_PIN)

#define FPAA_PROG_MAX_BYTES 3204 // based on the only file I have
#define FPAA_PROG_SCK_HZ 10000000 // 10 MHz for now

// I2S Configuration
#define I2S_BLK_PIN 18
#define I2S_WS_PIN 41
#define I2S_DATA_OUT_PIN 40
#define I2S_DATA_IN_PIN I2S_GPIO_UNUSED
#define I2S_SCLK_PIN 8

//Storage config (comment for internal flash)
//#define USE_SD_CARD
#define USE_SDMMC_MODE

// SDMMC Configuration (default for ESP32-WROVER-E)
#define SDMMC_CMD_PIN 6
#define SDMMC_CLK_PIN 7
#define SDMMC_D0_PIN 15
#define SDMMC_D1_PIN 16
#define SDMMC_D2_PIN 4
#define SDMMC_D3_PIN 5

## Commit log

2023-10-22 Initial commit: schematics for v0.1 as ordered
    [baluns.kicad_sch, dac.kicad_sch, esp32.kicad_sch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]
2023-10-24 added pdf and corrected some part values
    [dac.kicad_sch, fpaa_esp32_badge.kicad_sch, leds.kicad_sch]
2023-11-01 got web file management working with internal flash and FPAA program
    [partitions.csv]
2023-11-02 added interactive html bom
2023-11-02 Updated html bom with all values
    [fpaa_esp32_badge.kicad_pcb]
